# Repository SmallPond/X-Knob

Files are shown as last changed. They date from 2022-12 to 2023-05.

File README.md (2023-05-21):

<h1 align="center">X-Knob: A Smart Knob Based on LVGL UI Framework</h1>
<div align="center">








<!-- <img src="http://hits.dwyl.com/peng-zhihui/ElectronBot.svg" alt="Hits Badge"/> -->

<i>喜欢这个项目吗？请考虑给 Star ⭐️ 以帮助改进！</i>

</div>

---

[中文文档](README.md) ｜ [English](README_EN.md)

去年（2021）网上冲浪发现了 [smart_knob(SK)](https://github.com/scottbez1/smartknob)，心动不已。但一番了解后，马上被缺货的“天价”无刷电机劝退😅。最近在刷 B 站时发现 @455555菌 和 虫二大佬（@fywbcchong2）开源的 [Super Dial 电机旋钮屏](https://oshwhub.com/45coll/a2fff3c71f5d4de2b899c64b152d3da5)，这就到我动手玩一玩的时候了🤗。

Super Dial 电机旋钮屏替换了原 smart_knob 的“昂贵电机”且采用了直筒设计，个人觉得更为美观。

另外，smart_knob 的作者在项目中提到未来想使用 lvgl 来设计 UI。
> migrate to LVGL, for better display rendering and easy support for menus, etc. Shouldn't require a full 240x240x24b framebuffer in memory, freeing some for wifi, etc.

巧的是之前我玩过 X-TRACK，UI 极其丝滑。当时基于[稚晖君的 Peak ](https://github.com/peng-zhihui/Peak) 修改了部分硬件在 ESP32 上把玩了一番 [Deck](https://github.com/SmallPond/Deck)。因此，本项目将会是 Smart Knob + X-Track UI 的一个合成版。**故我称为它 X-Knob**。

### Demo video

[演示视频](https://www.bilibili.com/video/BV1N3411Z764/)

[智能家居控制演示视频](https://www.bilibili.com/video/BV1dg4y1H7vv/)

<a href="https://www.bilibili.com/video/BV1N3411Z764/">
    
</a>

### 3D CAD

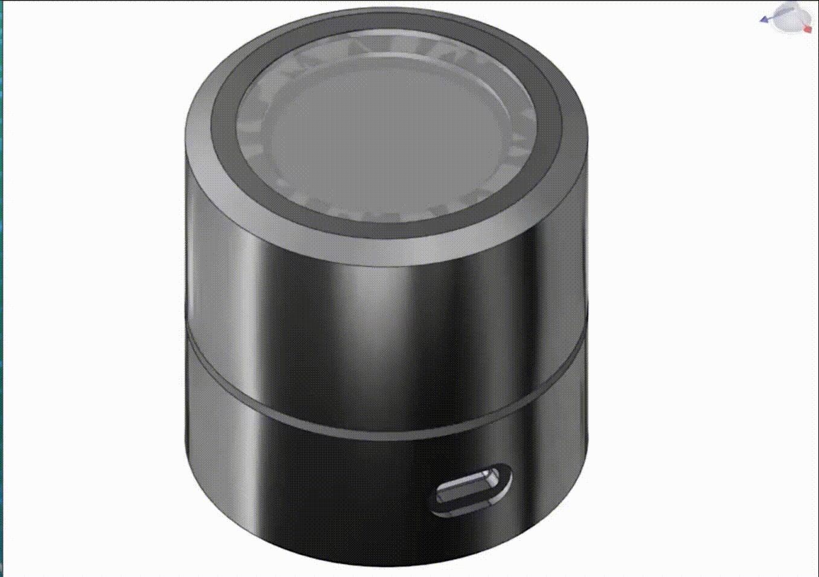
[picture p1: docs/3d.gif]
3d


> 上图（3D 装配图）来自[455555菌的视频](https://www.bilibili.com/video/BV1cG411c7QS/?vd_source=b234f79516f061233222cc1910681264)

主要硬件列表：
- 3 块 PCB：主控板 + 驱动板 + 屏幕板
- MCU: ESP32-S3 WROOM-1U-N16R8
- 屏幕: 240x240 圆形 LCD GC9A01 (1.28 寸) + 40.0mm 表蒙子 
- 磁编码器：MT6701CT
- 3205 无刷直流电机（无限位）（10 RMB）
- 602535 600mAh 锂电池 

X-KNOB 支持的特性：
- [x] X-TRACK UI 框架
- [x] 7 种旋钮模式：边界限制、棘轮、回弹等模式的组合
- [x] 实现基于 LVGL 框架下 smart-knob 的 UI 
- [x] Surface Dial 
- [x] 按键按压振动反馈 
- [x] 电源管理
  - 电池管理、系统深度休眠；
  - V2（最新） 硬件支持 UPS
  - 自动熄屏
- [x] X-Knob 通过 MQTT 接入 Home Assistant，可实现控制接入 HASS 的设备
- [x] 屏幕亮度调节、WiFi 和 MQTT 的 Web 配置
- [x] 支持 OTA 升级

待支持的特性：
- [ ] 基于 ESP32-S3 USB CDC 实现类似 Electron_Bot 的电脑配件模式

# Get Started

基本环境：
- VScode + PlatformIO
- [arduino-esp32](https://github.com/espressif/arduino-esp32) v2.0.5

1. 基本配置
```
git clone https://github.com/SmallPond/X-Knob.git

# 使用 PlatformIO 打开 Firmware 工程
# 重命名 src/secrets.h.example 文件为 src/secrets.h
# 并且修改相关配置：WiFi 密码，MQTT Server 等
cp src/secrets.h.example src/secrets.h

# （Option）修改 config.h 文件的 MQTT_HOST 为你的名字
# 该宏用来附带在 MQTT Topic 中
#define MQTT_HOST               "dingmos"      
```

2. 选择是否使用 MQTT 功能

若暂时不使用 MQTT 功能或没有配置好 WiFi 需要修改 platform.ini 文件来禁用 MQTT 功能

```
-DXK_MQTT=0 
``` 

这种方式将保留 Smart Home(S-Home)的 UI 供玩耍，但不会连接 WiFi 和调用 MQTT 发送消息。

3. 编译 && flash && enjoy 

关于固件下载的**注意事项** ：
- ESP32-S3 支持 USB 下载，可以在不拆开 X-knob 的情况下直接升级固件，参考[#5](https://github.com/SmallPond/X-Knob/issues/5) 
- 直接使用 Release 中的固件，flash 是需要偏移地址 `0x10000`，主要原因是 pio 编译出来的固件只包含 app 部分，而不含 bootloader 等部分。

# 实现记录
## LVGL

基于已有框架增添自己的图片：
- 图片生成C代码网站：[Online Image Converter BMP, JPG or PNG to C array or binary](https://lvgl.io/tools/imageconverter),选择 True color with alpha
- 将生成的C文件保存到`src\App\Resources\Image\`目录下
- 在 `src\App\Resources\ResourcePool.cpp` 增加一行声明
- Icons 素材网站：[iconoir](https://iconoir.com/)
  - Size: 42 x 42
  - Stroke Width: 1.6
  - Color: white

UI 设计工具：
- [NXP GUI Guider](https://www.nxp.com/design/software/development-software/gui-guider:GUI-GUIDER)
  
## SimpleFOC 
- [SimpleFOCStudio](https://github.com/JorgeMaker/SimpleFOCStudio)

## X-TRACK

### 消息通信机制

- `Subscribe/Unsubscribe`：订阅者向发布者发起/取消订阅
- `Publish`: 发布者向订阅者发布消息
  - 当发布者调用此函数时，消息通知框架将会依次调用各个订阅者通过`SetEventCallback()` 函数注册的回调函数。
- `Notify`: 订阅者向发布者主动发送消息
  - 当订阅者调用此函数时，消息通知框架将调用发布者通过`SetEventCallback()`函数注册的回调函数。
- `Pull`: 订阅者主动向发布者拉消息
  - 消息框架将调用发布者注册的回调函数。这种情况下，发布者注册的 callback 是判断`EVENT_SUB_PULL`事件，将信息填充到订阅者指定的 buf 中

个人理解：刚开始接触 X-TRACK 的消息通信框架时，看到 Subscribe 调用，以为这是标准的 Pub/Sub 模型，Pulblish 调用向所有订阅者发布消息，额外的 `Notify` 调用可以指定某个订阅者发送特定消息。但是实际用起来发现跟我想得不一样，Notify 调用是订阅者向发布者发送消息。所以这里的 Pub/Sub 更向是 Server/Client 的架构，Sub 通过 `Subscribe` 调用类似 client 的 `connect` 调用发起连接。不过对 publisher 来说， `publish` 调用省去了 server/client 模式下对 server 对 client 的管理逻辑。 

## 编译问题

问题：`sdkconfig.h no such file or directory`

原因：ESP32-S3 的支持需要 arduino-esp32 版本 >= 2.0.3，在 platformio 中需要对应安装 Espressif 32 >= 4.4.0 以上，我当前使用的是 5.2.0 版本，查看 platformio 安装目录下的文件`.platformio\platforms\espressif32\platform.json`可看到其对应使用 arduino-esp32 2.0.5 版本。

```c
    "framework-arduinoespressif32": {
      "type": "framework",
      "optional": true,
      "owner": "platformio",
      "version": "~3.20005.0"
    },
```

解决方案：`PIO Home -> Platforms -> Updates` 更新版本

# 参考项目

- [Hardware: Super Dial 电机旋钮屏](https://oshwhub.com/45coll/a2fff3c71f5d4de2b899c64b152d3da5)
- [Firmware: Super Dial 电机旋钮屏-gitee](https://gitee.com/coll45/super-dial-motor-knob-screen)
- [smart_knob](https://github.com/scottbez1/smartknob)
- [Super knob](https://gitee.com/wenzhengclub/super_knob)
- [X-TRACK](https://github.com/FASTSHIFT/X-TRACK)
- [Peak](https://github.com/peng-zhihui/Peak)
- [xiaomi_miot_raw](https://github.com/ha0y/xiaomi_miot_raw)

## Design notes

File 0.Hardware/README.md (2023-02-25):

硬件直接在立创 EDA 平台开源 [Hardware: Super Dial 电机旋钮屏](https://oshwhub.com/45coll/a2fff3c71f5d4de2b899c64b152d3da5)

主要硬件列表：
- MCU: ESP32-S3 WROOM-1U-N16R8
- 屏幕: 240x240 圆形 LCD GC9A01 (1.28 寸) + 40.0mm 表蒙子 
- 磁编码器：MT6701CT
- FPC 软天线 IPEX 1代
- 3205 无刷直流电机（无限位）（10 RMB）
- 电源管理
  - MT2492：5V - 3.3V
  - MT3609：电池升压到 5V
  - TP4054 锂电池充电
  - UPS

## 电源管理的基本原理

基本原理：

- PMOS 的开启电压 Vgs = Vg - Vs < 0
- NMOS 的开启电压 Vgs = Vg - Vs > 0
- 栅极（G）、源极(S)、漏极(D)

### 电源管理的实现

ESP32 运行期间，IO_ON_OFF 维持在高电平，Q11 导通；BATTERY_OFF 为低电平，Q10 截止；

PMOS G极被拉低，PMOS 导通，电池正常供电

1. Power OFF

BATTERY_OFF 拉高，电池电压高于 PUSH 的3.3V，Q10 导通，PMOS G 极被拉高，PMOS 截止，电池转 5V 停止工作

初始化 PUSH 引脚复用为 RTC ，在 deep sleep 模式下维持为上拉模式，直接由电池 BAT 供电

测试睡眠状态下：
- BATTERY_OFF 引脚电压为 1.15V 
- PUSH 引脚电压为 0.85V
- PMOS G 极电压等于电池电压（4.01V）

2. Power ON

PUSH 按键按下，电压拉低，Q10 导通，PMOS G 极被拉低，电池恢复供电。同时因为 PUSH 为低电平，ESP32 从 Deep Sleep 模式中被唤醒，重新初始化 IO_ON_OFF 引脚维持在高电平，确保 PMOS 一直处于导通状态。

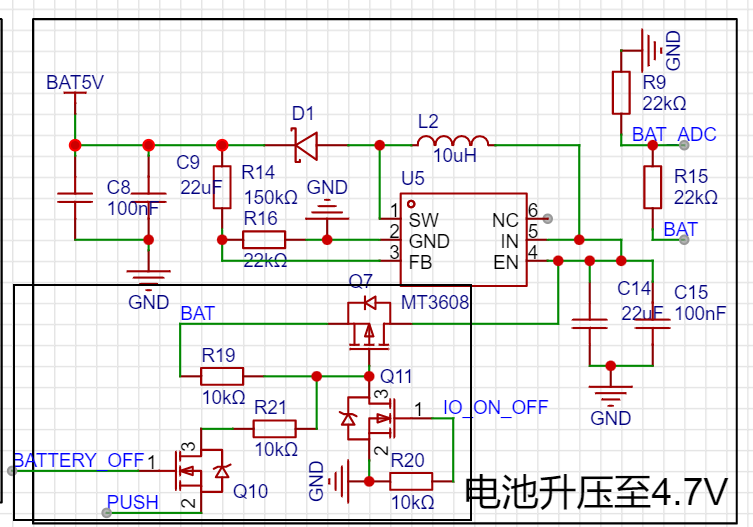
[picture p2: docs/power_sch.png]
power sch


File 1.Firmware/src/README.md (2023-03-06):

# 一些零碎的记录

lvgl/lvgl@^8.3.4

`Attempting MQTT connection` Error: 

```shell
E (28476) task_wdt: Task watchdog got triggered. The following tasks did not reset the watchdog in time:
E (28476) task_wdt:  - IDLE (CPU 0)
E (28476) task_wdt: Tasks currently running:
E (28476) task_wdt: CPU 0: LvglThread
E (28476) task_wdt: CPU 1: loopTask
E (28476) task_wdt: Aborting.
```

smart_knob 是一个有意思的、惊人的项目，我从 2021 年开始就关注到了，作者真的是太棒了。看到作者和项目中的 issues 中提到期望切换为 LVGL 来设计 UI、增加菜单、增加蓝牙和 WiFi 支持等需求，觉得非常有意思。所有我都尝试实现了一下并开源了，我称它为 X-Knob，主要特性如下：

- 基于 LVGL 重新实现了 smart_knob 的 UI
- 菜单功能
- 蓝牙：实现了兼容 Surface Dial 的功能，可控制 PC
- WiFi：基于 MQTT 实现了接入 Home Assistant 控制智能家居
- 电池供电：并且在硬件上支持 UPS（不间断电源）
- 使用货量充足的无刷电机和采用新的结构设计

不过很遗憾的是，我无法购买到 smart_knob 项目使用到的无刷电机，所以 X-Knob 没办法对 smart_knob 的硬件进行适配。同时，框架（LVGL）上的不一致，我无法将新增的代码合并到 smart_knob 主分支。

最后十分感谢 smart_konb 作者的开源，让我从中收获了乐趣，学习到了很多优秀的代码，认识了很多优秀的小伙伴。

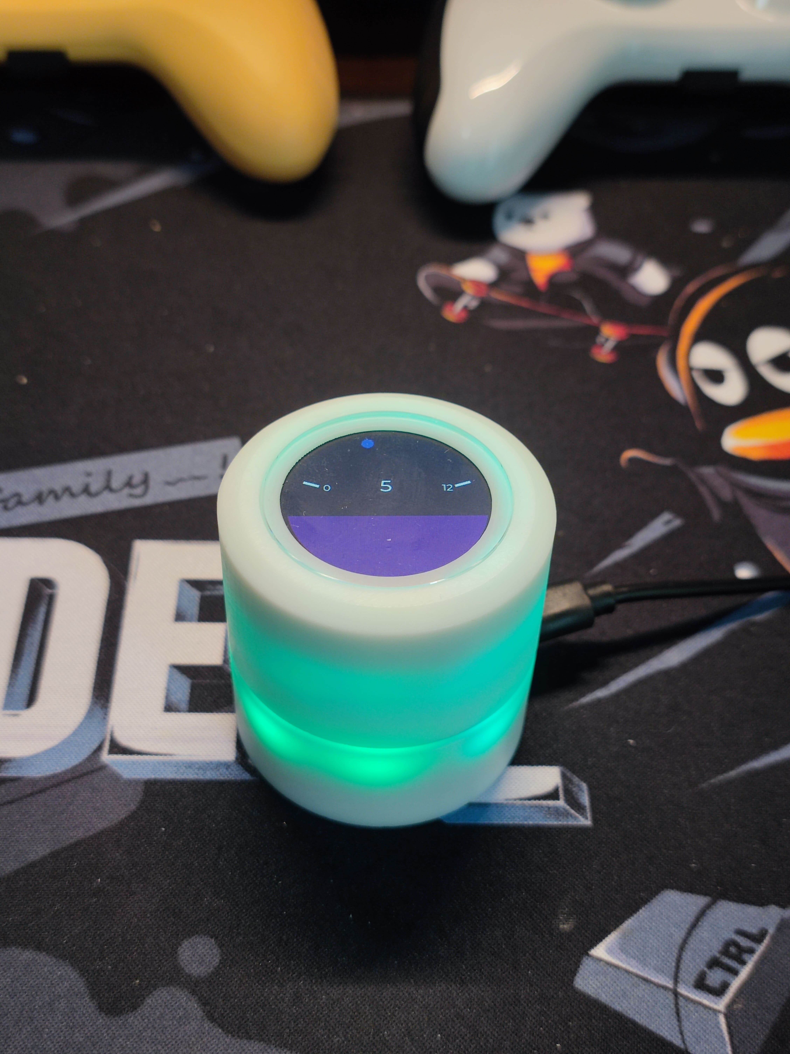
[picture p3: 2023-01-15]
docs/x-knob-sk.jpg

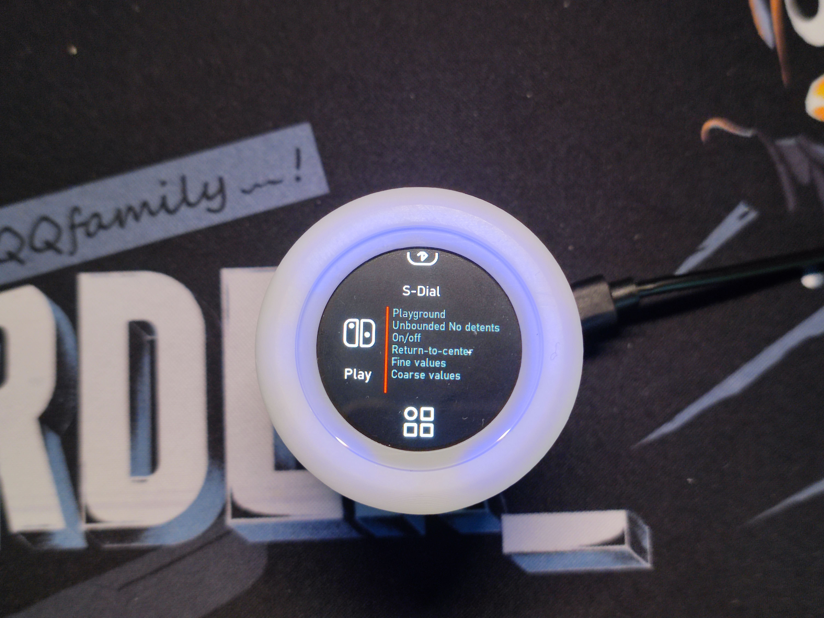
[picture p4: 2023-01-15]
docs/x-knob-xtrack.jpg

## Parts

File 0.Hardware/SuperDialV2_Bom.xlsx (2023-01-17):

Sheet: 元器件
SuperDial电机旋钮屏V2物料清单（元器件）
主控板 |  |  |  |  |  |  | 备注
序号 | 数量 | 名称 | 丝印 | 封装 | 值 | 立创链接
1 | 1 | KT-0603R | 3.3 | LED0603-R-RD |  | C2286 |  | 有
2 | 1 | HX25003-2A | B+ GND | CONN-TH_2P-P2.50_HX25003-2A |  | C442299 |  | 不需要-直接焊接
3 | 3 | CL10A226MQ8NRNC | C1,C6,C8 | C0603 | 22uF | C59461 |  | 有
4 | 5 | CC0603KRX7R9BB104 | C2,C5,C10,C11,C12 | C0603 | 100nF | C14663 |  | 有
5 | 4 | CL21A226MAQNNNE_C45783 | C3,C4,C7,C9 | C0805 | 22uF | C45783 | 耐压25V | 补一点
6 | 1 | HC-0.8-8PWT | CN2 | CONN-SMD_8P-P0.80_HCTL_HC-0.8-8PWT |  | C2845349 |  | 淘宝
7 | 1 | SWPA6045S100MT | L1 | IND-SMD_L6.0-W6.0_SWPA6045S | 10uH | C79272 |  | 立创
8 | 1 | MWSA0402S-1R0MT | L2 | IND-SMD_L4.4-W4.2 | 1uH | C408332 |  | 立创
9 | 8 | WS2812B-Mini_C527089 | LED1-LED9 | LED-SMD_4P-L3.5-W3.5-TL_WS2812B |  | C527089 | 3535，可不焊 | 有，拆
10 | 8 | 焊盘 | P1,P2,P3,P4,P5,P6,P7,P8 | 焊盘 |  |  | 无需买
11 | 2 | AP2300 | Q1,Q2 | SOT-23-3_L2.9-W1.3-P0.95-LS2.4-BR |  | C360338 |  | 优信电子
12 | 4 | 0603WAF4701T5E | R1,R3,R9,R17 | R0603 | 4.7kΩ | C23162 |  | 优信电子
13 | 9 | 0603WAF1002T5E | R2,R6,R7,R10,R12,R13,R14,R16,R19 | R0603 | 10kΩ | C25804 |  | 优信电子
14 | 1 | 0603WAF200KT5E | R4 | R0603 | 2Ω | C22977 |  | 优信电子
15 | 1 | 1206W4F500LT5E | R5 | R1206 | 500mΩ | C25340 |  | 立创
16 | 1 | 0603WAF2202T5E | R8 | R0603 | 22kΩ | C31850 |  | 优信电子
17 | 1 | 0603WAF1003T5E | R11 | R0603 | 100kΩ | C25803 |  | 有
18 | 1 | K2-1107ST-A4DW-06 | SW1 | KEY-SMD_L6.2-W3.6-LS8.0 |  | C118141 |  | 有
19 | 1 | TS-1068A-A2B3-D2 | SW2 | SW-SMD_L6.0-W6.0-LS8.0 |  | C498297 | 160g手感更佳 | 优信电子
20 | 1 | ESP32-S3-WROOM-1U-N16R8 | U1 | WIRELM-SMD_ESP32-S3-WROOM-1U |  | C3013946 | 淘宝买建议N16R8
21 | 1 | MT2492 | U2 | SOT-23-6_L2.9-W1.6-P0.95-LS2.8-BR |  | C89358 |  | 立创 | 降压
22 | 1 | IP5306 | U3 | ESOP-8_L4.9-W3.9-P1.27-LS6.0-BL-EP |  | C181692 |  | 优信电子 | 电源管理
23 | 1 | KH-TYPE-C-16P | USB1 | USB-C-SMD_KH-TYPE-C-16P |  | C709357 |  | 有
驱动板
序号 | 数量 | 名称 | 丝印 | 封装 | 值 | 立创链接
24 | 3 | CL21A226MAQNNNE_C45783 | C1,C2,C3 | C0805 | 22uF | C45783 | 耐压25V | 补一点
25 | 1 | CC0603KRX7R9BB104 | C4，C5 | C0603 | 100nF | C14663 |  | 有
26 | 1 | X0800WRS-03HF-LPV01 | CN1 | CONN-SMD_X0800WRS-03HF-LPV01 |  | C500138 |  | 淘宝
27 | 1 | HC-0.8-8PWT | CN2 | CONN-SMD_8P-P0.80_HCTL_HC-0.8-8PWT |  | C2845349 |  | 淘宝
28 | 6 | c | D1,D5,D6,D7,D8,D9 | SOD-123F_L2.7-W1.6-LS3.8-RD |  | C81598 |  | 优信电子
29 | 3 | FR107 | D2,D3,D4 | SOD-123FL_L2.7-W1.8-LS3.8-RD |  | C2760867 |  | 立创
30 | 6 | AP2300 | Q1,Q2,Q3,Q4,Q5,Q6 | SOT-23-3_L2.9-W1.3-P0.95-LS2.4-BR |  | C360338 |  | 立创
31 | 6 | 0603WAF100JT5E | R1,R4,R5,R6,R7,R8 | R0603 | 10Ω | C22859 |  | 优信电子
32 | 2 | 0603WAF4701T5E | R2,R3 | R0603 | 4.7kΩ | C23162 |  | 优信电子
33 | 1 | MT6701CT-STD | U1 | SOP-8_L4.9-W3.9-P1.27-LS6.0-BL |  | C2856764 |  | 淘宝
34 | 1 | EG2133 | U2 | TSSOP-20_L6.5-W4.4-P0.65-LS6.4-BL |  | C190343 |  | 淘宝
屏幕板
序号 | 数量 | 名称 | 丝印 | 封装 | 值 | 立创链接
35 | 1 | CC0603KRX7R9BB104 | C1 | C0603 | 100nF | C14663 |  | 优信电子
36 | 1 | HC-0.8-8PWT | CN2 | CONN-SMD_8P-P0.80_HCTL_HC-0.8-8PWT |  | C2845349 |  | 淘宝
37 | 1 | TFT_1.28_GC9A01_CB1.6-M18 | LCD1 | TFT_1.28_GC9A01_CB1.6-M18 |  |  | 淘宝买 | 已有
38 | 1 | AP2300 | Q4 | SOT-23-3_L2.9-W1.3-P0.95-LS2.4-BR |  | C360338 |  | 立创
39 | 1 | 0603WAF1002T5E | R2 | R0603 | 10kΩ | C25804 |  | 优信电子
40 | 2 | 0603WAF100JT5E | R1,R3 | R0603 | 10Ω | C22859 |  | 优信电子
 |  |  |  | r17 4.7k

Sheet: 打印或CNC
SuperDial电机旋钮屏V2物料清单（打印件）
除旋钮外，均不需要添加支撑
旋钮同时支持CNC加工和3D打印
详见stl文件和step文件

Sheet: 其他辅料
SuperDial电机旋钮屏V2物料清单（其他辅料） |  |  |  | 链接
序号 | 数量 | 名称 | 备注
1 | 1 | USB to TTL烧录器 | Wroom32烧录架也兼容
2 | 1 | 杜邦线若干 | 用于连接烧录器和主控
3 | 1 | 直径40mm厚度1mm玻璃 | 屏幕保护
4 | 4 | M2*2大平头螺丝 | 固定转子套
5 | 1 | M2.5*25六角铜柱双通 | 过屏幕线 | https://item.taobao.com/item.htm?spm=a1z09.2.0.0.7b032e8dFfj04J&id=586042823294&_u=e1sddf3s0c59
6 | 1 | 高温结构胶若干 | 固定电机和适配器
7 | 1 | 502胶若干 | 固定铜柱和适配器
8 | 4 | M1.6*4螺丝 | 固定适配器和驱动板
9 | 4 | M2高6.6飞控避震柱 | 套在半牙螺丝外
10 | 4 | M2*12内六角半牙螺丝 | 穿主控、避震柱和驱动，拧到适配器上
11 | 1 | 间距0.8mm 8P 32AWG单头线 | 屏幕线，长度约15cm
12 | 1 | 间距0.8mm 8P 32AWG双头同向线 | 连接驱动和主控，越短越好（可定制）
13 | 3 | M2*5螺丝 | 固定主控和底座
14 | 1 | 3205电机A款 无限位
15 | 1 | 2P杜邦线适量长度 | 连接主控和驱动
16 | 1 | 602535锂电池 600mAh | 可小不可大；不带插头、xh2.54和ph2.0均可（线长50mm）
17 | 1 | 0.15mm双面胶适量 | 固定屏幕
18 | 1 | FPC软天线IPEX 1代 | 贴在底座内壁（高度小于10，长度小于50）
19 | 1 | 直径54mm左右防滑硅胶垫 | 贴在底座底面（定制）
20 | 1 | M2.5*5螺丝 | 可辅助铜柱焊接（不买也行）
21
22
23
24
25
26
27
28
29
30
31
32
33
34

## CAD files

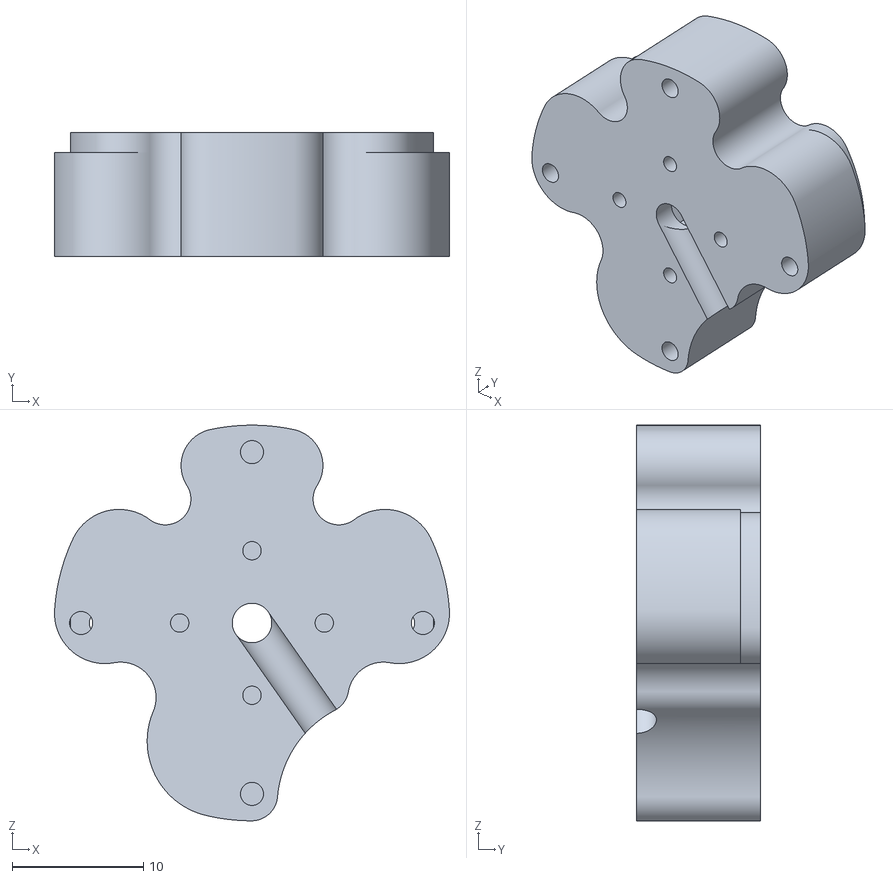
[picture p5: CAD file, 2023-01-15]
2.Model_3D/03.适配器.STL
30.0 x 9.40 x 30.1

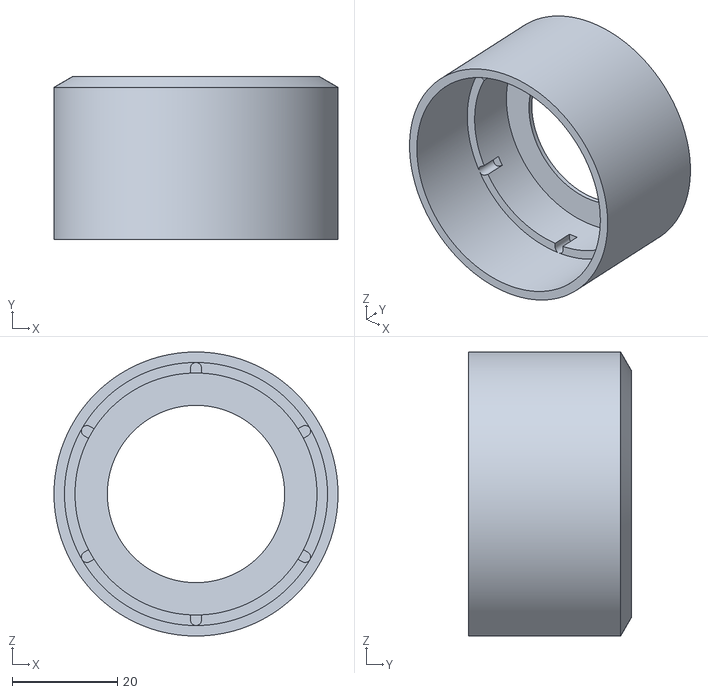
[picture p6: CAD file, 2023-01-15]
2.Model_3D/01.旋钮.STL
54.0 x 30.9 x 54.0

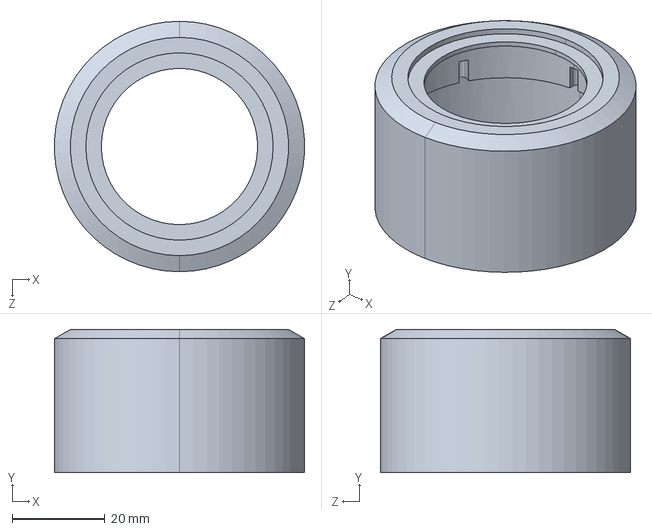
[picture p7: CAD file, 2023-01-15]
2.Model_3D/01.旋钮CNC用.STEP
53.9 x 30.9 x 54.0 mm

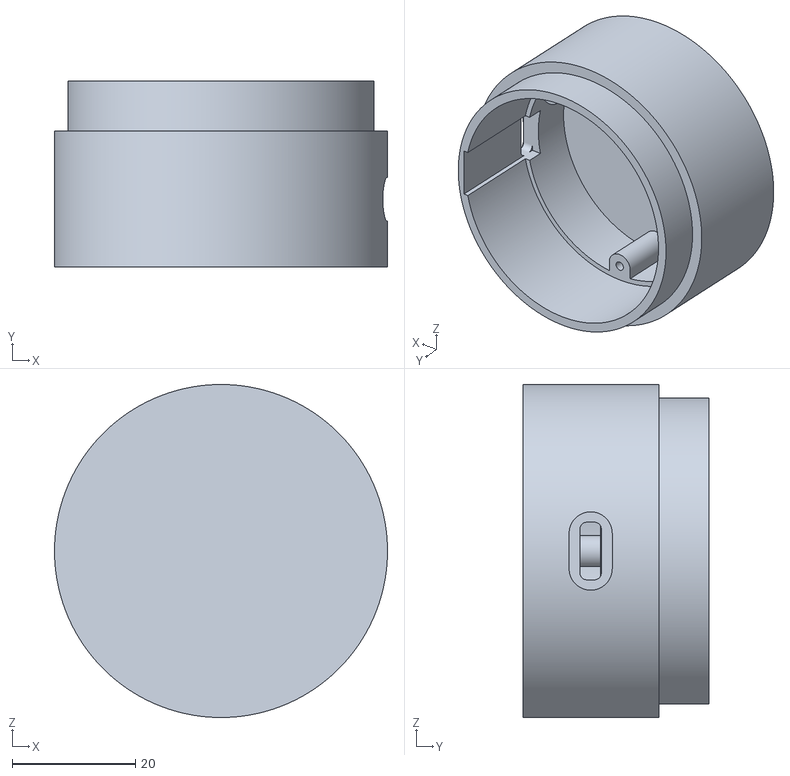
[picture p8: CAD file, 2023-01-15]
2.Model_3D/02.底座.STL
54.0 x 30.1 x 54.0

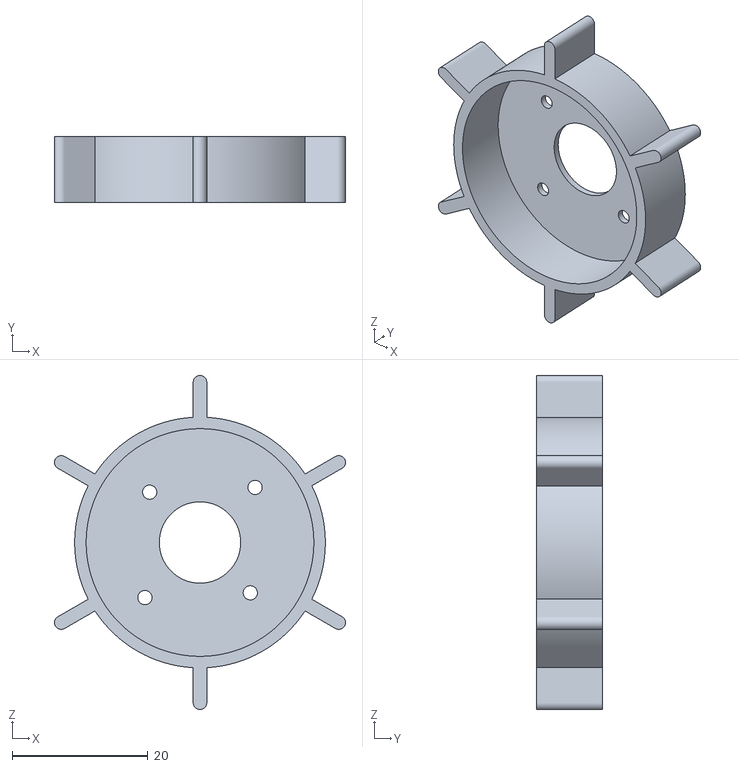
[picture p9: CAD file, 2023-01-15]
2.Model_3D/04.转子套.STL
43.0 x 9.80 x 49.3

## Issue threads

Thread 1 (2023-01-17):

程序编译错误

gzzz2008, 2023-01-17:
程序编译总是错误，不知道怎么修改？小白，望指点。
另外说硬件去电电容就可以USB链接，具体要去掉哪两个电容呢？

SmallPond, 2023-01-17:
能否给出编译错误信息呢，截图或粘贴信息？

电容是 C17 和 C18。

gzzz2008, 2023-01-17:
编译错误图片。
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

gzzz2008, 2023-01-17:
怎么没有找到C17和C18呢？在哪块板子上呢？

SmallPond, 2023-01-17:
> 编译错误图片。 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

应该是你 platformio 里的 ESP32 库版本太低了，还不支持esp32-s3开发板，如下图试试 5.2.0 或 4.4

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

> 怎么没有找到C17和C18呢？在哪块板子上呢？是不是C7和C8呢？

在原理图上是 C17 和 C18，PCB 上的丝印是 C10 和 C11

gzzz2008, 2023-01-18:
我看了一下ESp32的版本就是5.2.0啊。还有可能是其他的原因吗？

gzzz2008, 2023-01-18:
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
这是今天刚编译的，显示有这4处的错误。

SmallPond, 2023-01-18:
可以参考一下我 README中新增的“编译问题”说明，确认.platformio\platforms\espressif32\platform.json 文件中版本是否正确。这个问题我之前也遇到过，我就是更新版本就可以了。

如果还不行，建议在 platformio 先完全卸载 esp32 库再装一遍。

SmallPond, 2023-01-18:
另一个确认点是看 `./platformio/packages/framework-arduinoespressif32/tools/sdk/` 目录下是否有 `esp32s3/` 目录。

gzzz2008, 2023-01-18:
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
重新删除安装了一下，又出现这样的错误。

gzzz2008, 2023-01-18:
一定要编译吗？有没有封装好的，直接下载呢？

SmallPond, 2023-01-18:
不知道是否是你的中文路径有影响。这到了链接过程了，很好解决的，你可以试着自己解决一下。

> 一定要编译吗？有没有封装好的，直接下载呢？

我晚点发一个 release 吧。

Closed 2023-02-28.

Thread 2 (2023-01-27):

l老哥，嘉立创开源的那个是最新版的吗？那个bom能够直接用吗？

NereeScarlet, 2023-01-27:
如题
看到hardware文件里面的文档说嘉立创那有开源
想要问一下能不能用那个BOM
另外那个BOM的KT-0603RKENTO C2286 立创商城里面好像没有了？

NereeScarlet, 2023-01-27:
另外大佬pcb文件是哪个啊

NereeScarlet, 2023-01-27:
大佬，驱动板和屏幕板嘉立创显示不是嘉立创eda绘制的，不能用每月两张的那个免费打样券QAQ

NereeScarlet, 2023-01-27:
啊，解决了，只要在丝印那里随便加点啥就可以通过审核了。

SmallPond, 2023-01-28:
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

我就是用的那个开源方案和bom，应该是没问题的。

NereeScarlet, 2023-01-28:
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

多谢，我试试

Closed 2023-01-28.

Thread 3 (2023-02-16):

接入 Home Assistant 控制智能家居

SmallPond, 2023-02-16:
当前考虑使用 MQTT 接入，使用 HASS 的自动化配置触发条件。对应实现以下几个部分：

- 【UI】X-Knob 上增加智能家居控制界面，包括菜单选择项和控制界面
- HASS 配置 MQTT
- HASS 上增加自动化配置

SmallPond, 2023-02-20:
花了周末两天看 lvgl 文档。UI 已基本实现，使用 lvgl Flex 布局，滚动选择对应待控制的设备，色彩配置需要进一步优化

SmallPond, 2023-02-26:
已全部实现

Closed 2023-02-26.

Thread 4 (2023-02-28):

X-Knob 发现 Home Assistant 中的智能设备

SmallPond, 2023-02-28:
当前 X-Knob 控制的智能设备都是固化代码中的，未来期望在X-Knob 支持动态增加或删除智能设备，有两个方向：
- 和 Home Assistant 通过 MQTT 交互，Home Assistant 将设备发送给 X-Knob
- 制作一个上位机软件对 X-Knob 进行配置

目前更倾向第一种方向，但是暂时没有想到好的方案。

jwxa, 2023-03-01:
我这边看到两个可以参考的
1.HA有api接口的 HASS.agent电脑端控制就是走的这套 [项目地址](https://github.com/LAB02-Research/HASS.Agent)
2.巴法云插件同步米家的方式 选择实体同步 [项目地址](https://github.com/larry-wong/bemfa)

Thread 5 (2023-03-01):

您好，是否支持OTA升级固件

naja1977, 2023-03-01:
没有OTA升级的话，装配好之后极度不方便。串口无法引出外壳。

SmallPond, 2023-03-01:
是的，当前还没实现这一部分，后续将会加入 OTA 。

SmallPond, 2023-03-01:
通过这种方式可以让 X-Knob 自动进入下载模式，下载完成后会自动重启。

这样更加方便，也不用再给程序增加额外的 OTA 逻辑。所以当前不会考虑增加 WiFi OTA 了。

后续还要继续研究如何通过 platformio 传入这个参数，而不用这种 hack 模式。我参考文档试了一下在 platformio.ini 文件中增加参数会报错：
```bash
upload_flags =
	--before usb_reset
```

jwxa, 2023-03-01:
测试了一下 失败了
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

SmallPond, 2023-03-02:
> 我按45大佬指导的方式是直接ota(本来是45大佬的固件)刷入你的master分支代码编译后的firmware.bin文件

不知道你这里的最新master分支是否同步了我最新的 commit fc591806412a81dc00f394a2eb4f94ab179ea25e

由于我之前是把 usb 初始化了 cdc 设备，所以没办法通过 usb 直接下载，取消 cdc 的初始化就可以了。

所以，在这种情况下，你可能需要先手动刷入最新的固件，以后就可以通过 usb 下载了。

jwxa, 2023-03-02:
回家试试谢谢

Closed 2023-04-02.

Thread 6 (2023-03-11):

使用platfromio编译后内存占用过多

shuaizenge, 2023-03-11:
Advanced Memory Usage is available via "PlatformIO Home > Project Inspect"
Error: The program size (1769221 bytes) is greater than maximum allowed (1310720 bytes)
RAM:   [===       ]  28.5% (used 93400 bytes from 327680 bytes)
*** [checkprogsize] Explicit exit, status 1
Flash: [==========]  135.0% (used 1769221 bytes from 1310720 bytes)

编译后内存占用过多，超过100%不能烧录

shuaizenge, 2023-03-11:
目前我的解决方法是：
在platformio.ini中添加
board_build.partitions = partitions-no-ota.csv
board_build.f_cpu = 240000000L
board_build.f_flash = 80000000L
board_build.flash_mode = qio

新建立一个partitions-no-ota.csv文件
内容为：
# Name,   Type, SubType, Offset,  Size, Flags
nvs,      data, nvs,     0x9000,  0x5000,
otadata,  data, ota,     0xe000,  0x2000,
app0,     app,  ota_0,   0x10000, 0x300000,
spiffs,   data, spiffs,  0x310000,0xF0000,

SmallPond, 2023-03-12:
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

我编译的时候内存和 flash 都比你输出的大，不知道是否你修改了开发板配置呢？

Advanced Memory Usage is available via "PlatformIO Home > Project Inspect"
RAM: [===== ] 51.4% (used 168352 bytes from 327680 bytes)
Flash: [==== ] 43.4% (used 1451121 bytes from 3342336 bytes)

shuaizenge, 2023-03-12:
确实没有改配置，有空试试，谢谢啦

Closed 2023-03-14.

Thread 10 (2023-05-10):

Error: Unknown board ID 'esp32-s3-devkitc-1'

Bing-Study, 2023-05-10:
使用的的45君的硬件，为什么使用platform编译会出现这种错误

SmallPond, 2023-05-10:
贴下详细保存的截图呢，大概率是pio版本不对

Bing-Study, 2023-05-10:
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

SmallPond, 2023-05-10:
嗯...你贴的信息没有pio版本和arduino版本信息。  应该主要是这个问题，你可以更新到最新试试。

Closed 2023-05-11.

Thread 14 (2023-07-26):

关于X-Knob的编译和上传

twuking, 2023-07-26:
程序在下载之后停在了这个位置,没能进入主程序

编译环境
PlatformIO IDE
ESP32-S3-WROOM-1 16MB Flash, 8MB PSRAM
espressif32 6.3.2

mode:DIO, clock div:1
load:0x3fce3808,len:0x44c
load:0x403c9700,len:0xbe4
load:0x403cc700,len:0x2a38
entry 0x403c98d4
E (86) esp_core_dump_flash: No core dump partition found!
E (86) esp_core_dump_flash: No core dump partition found!

在readme中有提及,flash下载地址0x10000,请问如何在platform.ini中配置下载地址和下载bootload.
有尝试设置board_build.upload.offset_address = 0x10000 似乎没有起作用.

有了解的朋友,帮忙告知一下,谢谢.

SmallPond, 2023-08-02:
使用 pio  下载固件时不用做board_build.upload.offset_address修改，这里是用乐鑫的下载工具才用指定偏移

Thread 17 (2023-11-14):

对于ESP32芯片的代码来说需要修改那些地方呢？

xxjerryxx1014, 2023-11-14:
我做了一个是用ESP32芯片的，然后烧录的时候就报错了A fatal error occurred: This chip is ESP32 not ESP32-S3. Wrong --chip argument?，请问可以修改成针对此芯片的程序吗？

SmallPond, 2023-12-24:
可以修改，在 platformio.ini 文件中修改对对应的芯片就行。 但是引脚等相关配置你都需要再适配一下。

Closed 2023-12-24.

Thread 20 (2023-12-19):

WEB后台MQTT填写超长密码之后，进OTA功能会复位

Chillmax, 2023-12-19:
操作：
未填写WIFI名称和密码，直接填写MQTT服务器和账号密码等，密码是自动生成的128位随机字符字母数字，保存。
之后 每次进setting - OTA 四个点之后都会复位重启。
尝试0x10000地址重刷固件未恢复

SmallPond, 2023-12-19:
刷 1.3.1 版本也会这样吗？

Chillmax, 2023-12-20:
> 刷 1.3.1 版本也会这样吗？

是的，刷的releases里的[X-Knob_v1.3.1_merge.bin]

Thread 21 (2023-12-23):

创建.bin文件

Le-Duc0069, 2023-12-23:
我真的很喜欢你们的产品，非常好，你们能帮我创建一个 .bin 文件，以便我可以将其烧录为 esp32 吗？

SmallPond, 2023-12-24:
在 release 可以找到 bin 文件的

Le-Duc0069, 2023-12-25:
能问一下那个文件在哪里吗？

SmallPond, 2023-12-25:
https://github.com/SmallPond/X-Knob/releases

Le-Duc0069, 2023-12-28:
如果我想控制家里的多个设备，有没有办法添加更多设备？

SmallPond, 2023-12-29:
目前只能通过修改代码的方式，我已经封装好了函数，如果会的话增加起来很方便。 未来可能会增加网页配置方式。

Le-Duc0069, 2023-12-29:
希望尽快发布网页版

Closed 2023-12-24.

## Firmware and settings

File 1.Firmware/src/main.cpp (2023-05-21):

#include <Arduino.h>
#include "RGB.h"
#include "app/app.h"
#include "usb_cdc.h"
#include "app/ui/ui.h"
#include "hal/hal.h"
#include "hal/nvs.h"
#include "web/WiFiAsyncWebServer.h"

void push_handler(ButtonEvent* btn, int event)
{
    if (event == ButtonEvent::EVENT_PRESSED)
    {
        Serial.println("button pressed");
    } else if (event == ButtonEvent::EVENT_LONG_PRESSED) {
        Serial.println("button long pressed");
    } 
    if (event == ButtonEvent::EVENT_DOUBLE_CLICKED) {
        Serial.println("button double clicked");
    } else if (event == ButtonEvent::EVENT_SHORT_CLICKED) {
        Serial.println("button short clicked");
    } else if (event == ButtonEvent::EVENT_CLICKED) {
        Serial.println("button clicked"); 
    }
}

void setup() {
    HAL::Init();
    nvs_init();
    ffat_init();
    strip_init();
    // HWSerial.begin(115200);
    display_init();
    App_Init();
    // INIT_DONE();
}

void loop() {
    unsigned long currentMillis = millis();

    strip_start(currentMillis);

    HAL::Update();
    // delay(10);
}

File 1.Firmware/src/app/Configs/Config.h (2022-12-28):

#ifndef __CONFIG_H
#define __CONFIG_H

/*=========================
   Application configuration
 *=========================*/

#define CONFIG_SYSTEM_SAVE_FILE_PATH          "S:/SystemSave.json"
#define CONFIG_SYSTEM_LANGUAGE_DEFAULT        {'e','n','-','G','B'}
#define CONFIG_SYSTEM_GMT_OFFSET_DEFAULT      8 // GMT+ 8

#define CONFIG_WEIGHT_DEFAULT                 65 // kg

#define CONFIG_GPS_REFR_PERIOD                1000 // ms
#define CONFIG_GPS_LNG_DEFAULT                116.391332
#define CONFIG_GPS_LAT_DEFAULT                39.907415

#define CONFIG_TRACK_FILTER_OFFSET_THRESHOLD  2 // pixel
#define CONFIG_TRACK_RECORD_FILE_DIR_NAME     "Track"

#define CONFIG_MAP_USE_WGS84_DEFAULT          false

#define CONFIG_MAP_DIR_PATH                   {'/','M','A','P'}//"/MAP"

#define CONFIG_ARROW_THEME_DEFAULT            "default"

#define CONFIG_LIVE_MAP_LEVEL_DEFAULT         16
#define CONFIG_LIVE_MAP_VIEW_WIDTH            LV_HOR_RES
#define CONFIG_LIVE_MAP_VIEW_HEIGHT           LV_VER_RES

/* Simulator */
#define CONFIG_TRACK_VIRTUAL_GPX_FILE_PATH    "S:/TRK_20210801_203324.gpx"

/*=========================
   Hardware Configuration
 *=========================*/

#define NULL_PIN                    PD0

/* Screen */
// #define TFT_MISO 19
#define TFT_MOSI 11
#define TFT_SCLK 12
#define TFT_CS    10 
#define TFT_DC    14
#define TFT_RST   9  // Connect reset to ensure display initialises
#define CONFIG_SCREEN_BLK_PIN       13

#define CONFIG_SCREEN_HOR_RES       240
#define CONFIG_SCREEN_VER_RES       240
#define CONFIG_SCREEN_BUFFER_SIZE   (CONFIG_SCREEN_HOR_RES * CONFIG_SCREEN_VER_RES /2)

/* Battery */
#define CONFIG_BAT_DET_PIN          37
#define CONFIG_BAT_CHG_DET_PIN      38

/* Buzzer */
#define CONFIG_BUZZ_PIN             27
#define CONFIG_BUZZ_CHANNEL         2
#define CONFIG_SOUND_ENABLE_DEFAULT false

/* IMU */
#define CONFIG_IMU_INT1_PIN         32
#define CONFIG_IMU_INT2_PIN         33

/* I2C */
#define CONFIG_MCU_SDA_PIN          -1
#define CONFIG_MCU_SCL_PIN          -1

/* Encoder */
#define CONFIG_ENCODER_B_PIN        33 //34  Prev 
#define CONFIG_ENCODER_A_PIN        25 //35  Next
#define CONFIG_ENCODER_PUSH_PIN     12 // 27

/* Power */
#define CONFIG_POWER_EN_PIN         21

/* Debug USART */
#define CONFIG_DEBUG_SERIAL         Serial

/* SD CARD */
#define CONFIG_SD_SPI               SPI_SD
#define CONFIG_SD_CD_PIN            -1
#define CONFIG_SD_MOSI_PIN          -1
#define CONFIG_SD_MISO_PIN          -1 // PB14
#define CONFIG_SD_SCK_PIN           -1 // PB13
#define CONFIG_SD_CS_PIN            -1
#define CONFIG_SD_DET_PIN           22

/* Stack Info */
#define CONFIG_USE_STACK_INFO       0

#endif

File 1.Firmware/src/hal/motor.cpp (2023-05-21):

#include "hal/hal.h"
#include "motor.h"
#include <SimpleFOC.h>
#include "app/Accounts/Account_Master.h"

static const int spiClk = 1000000; // 400KHz
SPIClass* hspi = NULL;

BLDCMotor motor = BLDCMotor(7);
BLDCDriver3PWM driver = BLDCDriver3PWM(MO1, MO2, MO3);
//目标变量
float target_velocity = 0;

Account* actMotorStatus;

static XKnobConfig x_knob_configs[] = {
    // int32_t num_positions;        
    // int32_t position;             
    // float position_width_radians; 
    // float detent_strength_unit;  
    // float endstop_strength_unit;  
    // float snap_point;           
    // char descriptor[50]; 
    [MOTOR_UNBOUND_FINE_DETENTS] = {
        0,
        0,
        1 * PI / 180,
        2,
        1,
        1.1,
        "Fine values\nWith detents", //任意运动的控制  有阻尼 类似于机械旋钮
    },
    [MOTOR_UNBOUND_NO_DETENTS] = {
        0,
        0,
        1 * PI / 180,
        0,
        0.1,
        1.1,
        "Unbounded\nNo detents", //无限制  不制动
    },
    [MOTOR_SUPER_DIAL] = {
        0,
        0,
        5 * PI / 180,
        2,
        1,
        1.1,
        "Super Dial", //无限制  不制动
    },
    [MOTOR_UNBOUND_COARSE_DETENTS] = {
        .num_positions = 0,
        .position = 0,
        .position_width_radians = 8.225806452 * _PI / 180,
        .detent_strength_unit = 2.3,
        .endstop_strength_unit = 1,
        .snap_point = 1.1,
        "Fine values\nWith detents\nUnbound"
    },
    [MOTOR_BOUND_0_12_NO_DETENTS]= {
        13,
        0,
        10 * PI / 180,
        0,
        1,
        1.1,
        "Bounded 0-13\nNo detents",
    },
    [MOTOR_BOUND_LCD_BK_BRIGHTNESS]= {
        101,
        10,
        2 * PI / 180,
        2,
        1,
        1.1,
        "Bounded 0-101\nNo detents",
    },
    [MOTOR_BOUND_LCD_BK_TIMEOUT]= {
        31,
        0,
        5 * PI / 180,
        2,
        1,
        1.1,
        "Bounded 0-3601\nNo detents",
    },
    [MOTOR_COARSE_DETENTS] = {
        32,
        0,
        8.225806452 * PI / 180,
        2,
        1,
        1.1,
        "Coarse values\nStrong detents", //粗糙的棘轮 强阻尼
    },

    [MOTOR_FINE_NO_DETENTS] = {
        256,
        127,
        1 * PI / 180,
        0,
        1,
        1.1,
        "Fine values\nNo detents", //任意运动的控制  无阻尼
    },
    [MOTOR_ON_OFF_STRONG_DETENTS] = {
        2, 
        0,
        60 * PI / 180, 
        1,             
        1,
        0.55,                    // Note the snap point is slightly past the midpoint (0.5); compare to normal detents which use a snap point *past* the next value (i.e. > 1)
        "On/off\nStrong detent", //模拟开关  强制动
    },

};

XKnobConfig motor_config = {
    .num_positions = 0,
    .position = 0,
    .position_width_radians = 8.225806452 * _PI / 180,
    .detent_strength_unit = 2.3,
    .endstop_strength_unit = 1,
    .snap_point = 1.1,
};

// 死区制动百分率
static const float DEAD_ZONE_DETENT_PERCENT = 0.2;
// 死区RAD?
static const float DEAD_ZONE_RAD = 1 * _PI / 180;

// 怠速速度ewma alpha
static const float IDLE_VELOCITY_EWMA_ALPHA = 0.001;
// 怠速速度每秒钟弧度
static const float IDLE_VELOCITY_RAD_PER_SEC = 0.05;
// 怠速修正延迟millis
static const uint32_t IDLE_CORRECTION_DELAY_MILLIS = 500;
// 怠速校正最大角度rad
static const float IDLE_CORRECTION_MAX_ANGLE_RAD = 5 * PI / 180;
// 怠速修正率
static const float IDLE_CORRECTION_RATE_ALPHA = 0.0005;

// 当前相对位置
float current_detent_center = 0;
// 上次空闲开始状态
uint32_t last_idle_start = 0;
// 怠速检查速度
float idle_check_velocity_ewma = 0;

// 电机角度到当前位置的偏差
float angle_to_detent_center = 0;
//  ------------monitor--------------------
Commander commander = Commander(Serial, '\n', false);
void onPid(char* cmd){commander.pid(&motor.PID_velocity, cmd);}
void onMotor(char* cmd){commander.motor(&motor, cmd);}
// -------------monitor--------------------
//目标变量
static float readMySensorCallback(void) {
    hspi->beginTransaction(SPISettings(spiClk, MSBFIRST, SPI_MODE0));
    digitalWrite(hspi->pinSS(), LOW);  // pull SS slow to prep other end for transfer
    uint16_t ag = hspi->transfer16(0);
    digitalWrite(hspi->pinSS(), HIGH); // pull ss high to signify end of data transfer
    hspi->endTransaction();
    ag = ag >> 2;
    float rad = (float)ag * 2 * PI / 16384;
    if (rad < 0) {
        rad += 2 * PI;
    }
    return rad;
}
static void initMySensorCallback(void) {
    hspi = new SPIClass(HSPI);
    hspi->begin(MT6701_SCL, MT6701_SDA, -1, MT6701_SS); //SCLK, MISO, MOSI, SS
    pinMode(hspi->pinSS(), OUTPUT); //HSPI SS
}


GenericSensor sensor = GenericSensor(readMySensorCallback, initMySensorCallback);

/* 
 * 将随机变化的值限制在一个给定的区间[min,max]内
*/ 
static float CLAMP(const float value, const float low, const float high)
{
    return value < low ? low : (value > high ? high : value);
}

void HAL::motor_shake(int strength, int delay_time)
{
    motor.move(strength);
    for (int i = 0; i < delay_time; i++)
    {
        motor.loopFOC();
        vTaskDelay(1);
    }
    motor.move(-strength);
    for (int i = 0; i < delay_time; i++)
    {
        motor.loopFOC();
        vTaskDelay(1);
    }
}


int HAL::get_motor_position(void)
{
    return motor_config.position;
}

void HAL::update_motor_mode(int mode , int init_position)
{
    motor_config = x_knob_configs[mode];
    motor_config.position = init_position;
    #if XK_INVERT_ROTATION
        current_detent_center = -motor.shaft_angle;
    #else 
        current_detent_center = motor.shaft_angle;
    #endif
}

static void motor_status_publish(bool is_outbound)
{
    // position
    static int32_t last_position = 0;

    if (is_outbound || motor_config.position != last_position) {
        MotorStatusInfo info = {
            .is_outbound = is_outbound,
            .position = motor_config.position,
            .angle_offset = angle_to_detent_center * 180 / PI,  // 转换为角度
        };
        actMotorStatus->Commit((const void*)&info, sizeof(MotorStatusInfo));
        actMotorStatus->Publish();
        last_position = motor_config.position;
    }
    
}
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

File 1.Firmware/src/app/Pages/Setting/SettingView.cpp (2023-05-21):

#include "SettingView.h"
#include "Setting.h"
#include "SettingModel.h"

using namespace Page;
#define ITEM_PAD 60
/*
* 默认视图显示： 圆点，原点所在位置 label_value
* 此函数根据需要增加或 hidden 对象
*/
void SettingView::SetPlaygroundMode(int16_t mode)
{
    // lv_label_set_text(ui.label_value, "Smart Home");
    lv_meter_set_scale_ticks(ui.meter, ui.scale_pot, 73, 2, 0, lv_color_make(0xff, 0x00, 0x00));
    lv_meter_set_scale_range(ui.meter, ui.scale_pot, 0, 72, 360, 270);
    SetWiFiViewVisible(false);
    switch(mode){
        case DEFAULT_VIEW:
            PlaygroundView::DefaultView();
            break;
        case WIFI_SETTING_VIEW:
            SetWiFiViewVisible(true);
            break;
        case LCD_BK_TIMEOUT_SETTING_VIEW:
            MIN_VALUE = 0;
            MAX_VALUE = 30;
            SCALE_LEFT_BOUND_TICKS = 220;
            SCALE_ANGLE_RANGE = 100;
            PlaygroundView::BoundZeroView();
            lv_obj_clear_flag(ui.label_value, LV_OBJ_FLAG_HIDDEN);
            break;
        case LCD_BK_BRIGHTNESS_SETTING_VIEW:
            MIN_VALUE = 10;
            MAX_VALUE = 100;
            SCALE_LEFT_BOUND_TICKS = 220;
            SCALE_ANGLE_RANGE = 100;
            PlaygroundView::BoundZeroView();
            lv_obj_clear_flag(ui.label_value, LV_OBJ_FLAG_HIDDEN);
            break;
        default:
            lv_obj_add_flag(ui.label_value, LV_OBJ_FLAG_HIDDEN);
            break;
    }
}

void SettingView::UpdateFocusedSetting(const char* name)
{
    lv_label_set_text(m_ui->foucs_label, name );
}

void SettingView::SetCtrView(lv_obj_t* obj)
{
    setting_t *setting = setting_map[obj];
    
    switch (setting->num) {
        case DEFAULT_VIEW:
            PlaygroundView::DefaultView();
            break;
        case WIFI_SETTING_VIEW:
            break;
        case LCD_BK_TIMEOUT_SETTING_VIEW:
            current_view = LCD_BK_TIMEOUT_SETTING_VIEW;
            break;
        case LCD_BK_BRIGHTNESS_SETTING_VIEW:
            current_view = LCD_BK_BRIGHTNESS_SETTING_VIEW;
            break;
        default:
            break;
    }
    printf("set view: %d\n",current_view);
    lv_obj_set_style_bg_opa(obj, LV_OPA_COVER, 0);
}
/*
* Gets the name of the controlled setting
*/
char* SettingView::GetEditedSettingName(void)
{
    std::map<lv_obj_t*, setting_t *>::iterator iter;
    iter = setting_map.begin();
    while(iter != setting_map.end()) {
        if (lv_obj_has_state(iter->first, LV_STATE_EDITED)) {
            lv_obj_t* label = lv_obj_get_child(iter->first, 1);
            if (label != NULL) {
                return lv_label_get_text(label);
            }
        }
        iter++;
    }
    return NULL;
}

//回到選單
void SettingView::ClearCtrView(lv_obj_t *obj)
{
    setting_t *setting = setting_map[obj];
    printf("back to setting menu\n");
    current_view = DEFAULT_VIEW;
    PlaygroundView::DefaultView();
    lv_obj_set_style_bg_opa(obj, LV_OPA_TRANSP, 0);
}

int SettingView::GetViewMode(void)
{
    return current_view;
}


void SettingView::UpdateCtrlView(SettingInfo* info)
{
    int _value = 0;
    int32_t motor_pos = info->motor_pos;
    lv_meter_set_indicator_value(ui.meter, ui.nd_img_circle, motor_pos);
    switch (current_view) {
        case DEFAULT_VIEW:
            break;
        case WIFI_SETTING_VIEW:
            break;
        case LCD_BK_TIMEOUT_SETTING_VIEW:
            _value = info->xkonb_value;
            SettingView::UpdateBackgroundView(info);
            lv_label_set_text_fmt(
                ui.label_value,
                "%dmin",
                _value
            );
            lv_meter_set_indicator_value(ui.meter, ui.nd_img_circle,  _value );
            break;
        case LCD_BK_BRIGHTNESS_SETTING_VIEW:
            _value = info->xkonb_value;
            SettingView::UpdateBackgroundView(info);
            lv_label_set_text_fmt(
                ui.label_value,
                "%d",
                _value
            );
            lv_meter_set_indicator_value(ui.meter, ui.nd_img_circle,  _value );
            break;
        default:
            break;
    }
}
void SettingView::UpdateView(SettingInfo* info)
{
    if (current_view) {
        UpdateCtrlView(info);
        return;
    }
    int32_t motor_pos = info->motor_pos;
    motor_pos = motor_pos % (360/5); // 5 为surface dial 电机模式最小角度
    if (motor_pos < 0) {
        motor_pos = 360/5 + motor_pos;
    }
    lv_meter_set_indicator_value(ui.meter, ui.nd_img_circle, motor_pos);
}

void SettingView::SetWiFiViewVisible(bool visible) 
{
    if(visible){
        lv_obj_clear_flag(m_ui->wifi, LV_OBJ_FLAG_HIDDEN);
        lv_obj_add_flag(m_ui->cont_row, LV_OBJ_FLAG_HIDDEN);
        lv_obj_add_flag(m_ui->foucs_label, LV_OBJ_FLAG_HIDDEN);
    }else{
        lv_obj_clear_flag(m_ui->cont_row, LV_OBJ_FLAG_HIDDEN);
        lv_obj_clear_flag(m_ui->foucs_label, LV_OBJ_FLAG_HIDDEN);
        lv_obj_add_flag(m_ui->wifi, LV_OBJ_FLAG_HIDDEN);
    }
}
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

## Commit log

2022-12-17 add led ring strip
2022-12-25 add push button driver
2022-12-28 add X-track ui platform
2022-12-28 motor driver: SimpleFOC 2.2.3
2023-01-02 [ui] add dialpad and switch img
2023-01-02 [hal] change motor init process
2023-01-02 [ui] fix template timer error
2023-01-02 [lvgl] modified push button indev interface
2023-01-03 [hal] pin lvgl task and motor task to specific core.
2023-01-03 [hal] bugfix: must remove log(serial.printf) in motor task
    [motor.cpp]
2023-01-05 [hal] simplefoc: use Monitoring and fixed motor spins wildly.
    [motor.cpp]
2023-01-07 [msg][motor] the mode of the motor can be controlled via messages in the MENU.
2023-01-07 [motor] Contains the following big changes: PID, Commander and Account
    1. Adjust the PID parameters of the motor after analyzing the working mode of the SK
    2. add simplefoc Commander to tune the velocity PID
    3. MotorStatus to publish motor position
2023-01-08 [hal] motor: support INVERT_ROTATION
2023-01-08 [hal] motor: add new mode and publish more motor status to playground
2023-01-08 [ui] add ON/OFF mode; now can return memu page and switch to Playground
2023-01-10 [ui] modify the default display of the playground: no background color fill; fix motor shake by removing logs
2023-01-12 [ui] redefine the mapping between app and motor mode.
2023-01-13 [motor] remove monitoring
2023-01-13 [app] make a new motor config for super-dial
2023-01-13 bugfix: add break in case PLAYGROUND_MODE_ON_OFF
2023-01-15 update README.md： add git and pic
2023-01-15 [Hardware] ADD hardware and 3D Model.
    [01.旋钮.STL, 01.旋钮CNC用.STEP, 02.底座.STL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]
2023-01-17 [Hardware] Updated README.md and added some hardware information
    [SuperDialV2_Bom.xlsx]
2023-02-17 [app][lvgl] redefine encoder long press time and repeat time.
2023-02-25 [HAL] Support power management <power off>
2023-02-25 [app] In the system interface, we can enter the power off state
2023-02-25 [HAL] lvgl: temperily disable encoder diff
2023-02-25 fixme: Page switching fails when the Delete function on playground is declared virtual (polymorphic).
2023-02-26 [HASS] Add control logic and configure motor mode
2023-02-26 [APP] ohhh. we can control xiaomi device now!
2023-02-28 Replace App to app
    [ACT_Motor.cpp, Menu.cpp]
2023-03-01 [flash] remove usb cdc init, support usb dowload(flash), fixes #5
    https://github.com/SmallPond/X-Knob/issues/5
    [main.cpp]
2023-04-22 fix spelling error: lable should be replaced with label.
    [HassView.cpp]
2023-04-29 [app] The Hass app supports dynamic multi-device and fixed issues regarding press control and long press conflicts.
    [Hass.cpp, HassView.cpp, Menu.cpp]
2023-05-06 [app] Fix the issue of Surface Dial app unable to connect properly when re-entering. #9
    [SurfaceDial.cpp]
2023-05-21 [app] setting page
    fix HassView note format
    add a space between function two parameters
    replace tab with space in main
    update lcd bk thread name
    remove spaces between function variables
    use define to set config default value
    format hassview
    fix setting view display text
    update setting icon size
    [ACT_Motor.cpp, Hass.cpp, Menu.cpp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]
2023-05-22 [project] Fix compilation issues in Linux env(filename case sensitivity in Linux.)
    [ACT_Motor.cpp]
